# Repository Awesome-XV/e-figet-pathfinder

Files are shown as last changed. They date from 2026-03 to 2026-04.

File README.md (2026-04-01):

# e-figet-pathfinder
This is a project that allows you to play around with switches and LED's. It's a reaction game ... for now, I am planning to make a settings/page button that allows you to play different game modes and stuff. But now it's geared toward an *F1* style gameplay where the LED's close in on the center light and then they all go blank and it measures the time for you to let go of the "clutch" and hit the "accelerator". Maybe different racing types later??
I made this project as an intro into PCB's, circuits and soldering because it's my first physical project that I have done. I wanted to get into the hardware project and there was a nice guide, but no soldering guide so I get to do that on my own. So this is a bit later, and I added a battery compartment to it, it's now a mobile device and it doesn't have to be plugged in. I also am now planning to add a GT practice shifter to the code where you can practice shifting GT style. I also had to add 2 connectors so that I can solder the battery wires correctly.

# Some Pics





# BOM Table
| Name | Purpose | Quantity | Total Cost (USD) | Distributor | Link |
|---|---|:---:|---:|---|---|
| XIAO RP2040 | MC, controls everything | 1 | $4.68 | Digikey | [Buy](https://www.digikey.com/en/products/detail/seeed-technology-co-ltd/102010428/14672129) |
| LED RED 5MM | Lights up | 7 | $1.05 | Digikey | [Buy](https://www.digikey.com/en/products/detail/w%C3%BCrth-elektronik/151051RS11000/4490012) |
| Through Hole Resistors | For the LEDs | 10 | $0.22 | Digikey | [Buy](https://www.digikey.com/en/products/detail/stackpole-electronics-inc/CF18JT110R/1741570) |
| MX SWITCH 12V | Switch to trigger actions | 4 | $5.00 | Digikey | [Buy](https://www.digikey.com/en/products/detail/cherry-americas-llc/MX1A-C1NW/280855) |
| BLACK KEYCAPS | Keycaps for the MX switches | 1 | $5.95 | Digikey | [Buy](https://www.digikey.com/en/products/detail/adafruit-industries-llc/4997/14552180) |
| Battery Compartment | To hold the batteries | 1 | $1.77 | Digikey | [Buy](https://www.digikey.com/en/products/detail/keystone-electronics/2465/303814) |
| Connectors | To provide a place for the red and black wires to hook onto | 10 | $0.29 | Digikey | [Buy](https://www.digikey.com/en/products/detail/adam-tech/PH1-01-UA/9830231) |
| Diode | To prevent reverse current flow | 1 | $0.18 | Digikey | [Buy](https://www.digikey.com/en/products/detail/smc-diode-solutions/1N5817/21705460) |
| PCB | For connection | 1 | $2.00 | JLCPCB | N/A |
| Shipping | Move these parts | 1 | $10.29 | JLCPCB, Digikey | N/A |
| Tax | I have to pay | 1 | $2.22 | Digikey | N/A |
| Tariffs | Quantity means 5 products I have tax on | 5 | $0.79 | Digikey | N/A |
| **Total** | | | *$34.44* | | |

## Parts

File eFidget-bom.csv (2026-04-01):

Name | Purpose | Quantity | Total Cost (USD) | Link | Distributor
Connectors | To provide a place for the red and black wires to hook onto | 10 | 0.29 | https://www.digikey.com/en/products/detail/adam-tech/PH1-01-UA/9830231 | Digikey
Diode | To prevent reverse current flow | 1 | 0.18 | https://www.digikey.com/en/products/detail/smc-diode-solutions/1N5817/21705460 | Digikey
Through Hole Resistors | For the LEDS | 10 | 0.22 | https://www.digikey.com/en/products/detail/stackpole-electronics-inc/CF18JT110R/1741570 | Digikey
Battery Compartment | To hold the batteries | 1 | 1.77 | https://www.digikey.com/en/products/detail/keystone-electronics/2465/303814 | Digikey
Tax | I have to pay this | 1 | 2.22 |  | Digikey
Tarrifs | Worse version of tax (quantity means 5 products I have tax on) | 5 | 0.79 |  | Digikey
XIAO RP2040 | MC, controls everything | 1 | 4.68 | https://www.digikey.com/en/products/detail/seeed-technology-co-ltd/102010428/14672129 | Digikey
MX SWITCH 12V | Switch to trigger actions | 4 | 5.00 | https://www.digikey.com/en/products/detail/cherry-americas-llc/MX1A-C1NW/280855 | Digikey
BLACK KEYCAPS | Keycaps for the MX switches | 1 | 5.95 | https://www.digikey.com/en/products/detail/adafruit-industries-llc/4997/14552180 | Digikey
LED RED 5MM | Lights up | 7 | 1.05 | https://www.digikey.com/en/products/detail/w%C3%BCrth-elektronik/151051RS11000/4490012 | Digikey
Shipping | Move these parts! | 1 | 10.29 |  | JLCPCB, Digikey
PCB | For connection! | 1 | 2.00 |  | JLCPCB

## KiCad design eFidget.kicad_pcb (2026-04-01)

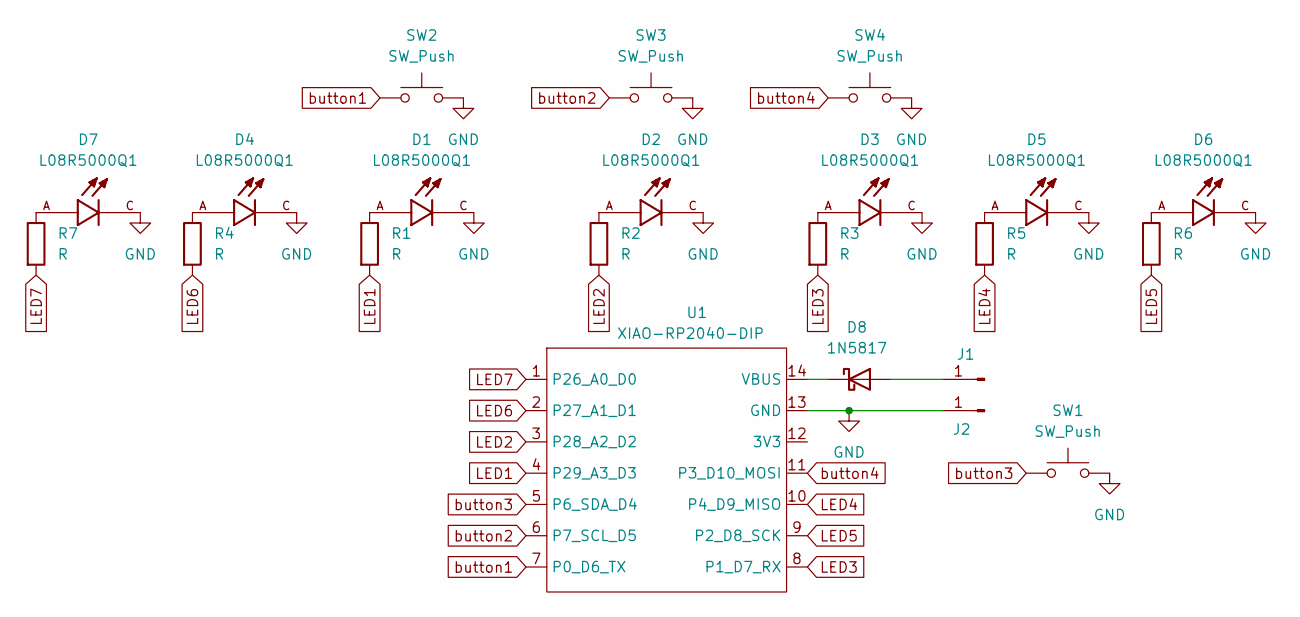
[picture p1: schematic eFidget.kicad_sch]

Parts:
D1, D2, D3, D4, D5, D6, D7: L08R5000Q1; LEDRD254W57D500H1070; PARTREV NA
D8: 1N5817; D_DO-41_SOD81_P10.16mm_Horizontal
J1, J2: Conn_01x01_Pin; PinHeader_1x01_P2.54mm_Vertical
R1, R2, R3, R4, R5, R6, R7: R; R_Axial_DIN0204_L3.6mm_D1.6mm_P5.08mm_Horizontal
SW1, SW2, SW3, SW4: SW_Push; SW_Cherry_MX_1.00u_PCB
U1: XIAO-RP2040-DIP

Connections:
GND: D1.C, D2.C, D3.C, D4.C, D5.C, D6.C, D7.C, J2.1, SW1.2, SW2.2, SW3.2, SW4.2, U1.13 (GND)
LED1: R1.2, U1.4 (P29_A3_D3)
LED2: R2.2, U1.3 (P28_A2_D2)
LED3: R3.2, U1.8 (P1_D7_RX)
LED4: R5.2, U1.10 (P4_D9_MISO)
LED5: R6.2, U1.9 (P2_D8_SCK)
LED6: R4.2, U1.2 (P27_A1_D1)
LED7: R7.2, U1.1 (P26_A0_D0)
unnamed: D1.A, R1.1
unnamed: D2.A, R2.1
unnamed: D3.A, R3.1
unnamed: D4.A, R4.1
unnamed: D5.A, R5.1
unnamed: D6.A, R6.1
unnamed: D7.A, R7.1
unnamed: D8.2 (A), J1.1
unnamed: D8.1 (K), U1.14 (VBUS)
button1: SW2.1, U1.7 (P0_D6_TX)
button2: SW3.1, U1.6 (P7_SCL_D5)
button3: SW1.1, U1.5 (P6_SDA_D4)
button4: SW4.1, U1.11 (P3_D10_MOSI)

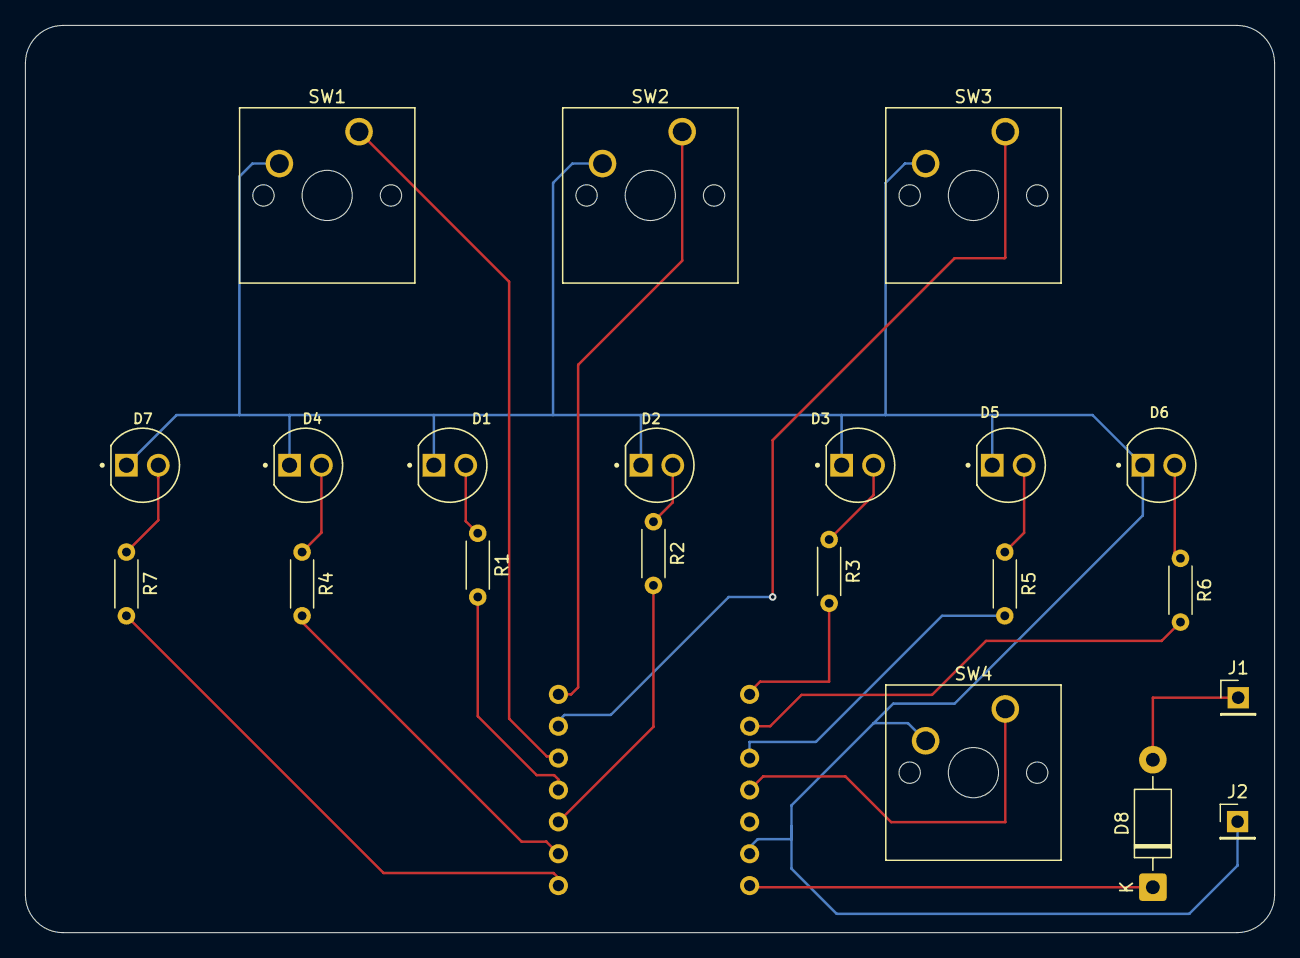
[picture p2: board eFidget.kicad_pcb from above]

Board: 2 copper layers, 99.5 x 72.3 mm, 22 parts (1 on the bottom side), 21 nets.

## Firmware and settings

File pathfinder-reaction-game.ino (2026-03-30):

// Quick Map of the pins for refrence
// D0 = Led 7 (Most right)
// D9 = Led 4
// D3 = Led 1
// D2 = Led 2 (Center)
// D7 = Led 3
// D8 = Led 5
// D1 = Led 6 (Most Left)

// D6 = Switch 1 (clutch)
// D5 = Switch 2 (TBD)
// D4 = Switch 3(accelerate)
// D10 = Switch 4 (Start)

const int LED_COUNT = 7;
const int LEDS[7] = { D0, D1, D9, D2, D3, D8, D7 };
const int BTN_CLUTCH = D6;
const int BTN_ACCELERATE = D4;
const int BTN_START = D5;

const int STEP = 800;
const int MIN_HOLD = 500;
const int MAX_HOLD = 7000;
const int TIMEOUT = 5000;

void allOn() {
  for (int i = 0; i < LED_COUNT; i++) {
    digitalWrite(LEDS[i], HIGH);
  }
}

void allOff() {
  for (int i = 0; i < LED_COUNT; i++) {
    digitalWrite(LEDS[i], LOW);
  }
}

void keyPress(int pin) {
  while (digitalRead(pin) == HIGH) {
    delay(5);
  }
}

void keyRelease(int pin) {
  while (digitalRead(pin) == LOW) {
    delay(5);
  }
}

void falseStart() {
  allOff();
}

bool checkFalseStart() {
  if (digitalRead(BTN_ACCELERATE) == LOW) {
    falseStart();
    return true;
  }

  if (digitalRead(BTN_CLUTCH) == HIGH) {
    falseStart();
    return true;
  }

  return false;
}

void showResult(long reactionTime) {
  char digits[8];
  sprintf(digits, "%07ld", reactionTime);
  for (int i = 0; i < 7; i++) {
    int count = digits[i] - '0';

    if (count == 0) continue;
    for (int x = 0; x < count; x++) {
      digitalWrite(LEDS[i], HIGH);
      delay(250);
      digitalWrite(LEDS[i], LOW);
      delay(200);
    }

    delay(500);
  }
}

void setup() {
  Serial.begin(115200);
  for (int i = 0; i < LED_COUNT; i++) {
    pinMode(LEDS[i], OUTPUT);
    digitalWrite(LEDS[i], LOW);
  }

  pinMode(BTN_START, INPUT_PULLUP);
  pinMode(BTN_CLUTCH, INPUT_PULLUP);
  pinMode(BTN_ACCELERATE, INPUT_PULLUP);

  randomSeed(analogRead(A3));
  for (int i = 0; i < LED_COUNT; i++) {
    digitalWrite(LEDS[i], HIGH);
    delay(80);
  }

  delay(300);
  allOff();
}

void loop() {
  while (digitalRead(BTN_START) == HIGH || digitalRead(BTN_CLUTCH) == HIGH) {
    delay(5);
  }

  keyRelease(BTN_START);
  delay(500);

  int seqL[4] = {0, 1, 2, 3};
  int seqR[4] = {6, 5, 4, 3};

  for (int step = 0; step < 3; step++) {
    digitalWrite(LEDS[seqL[step]], HIGH);
    digitalWrite(LEDS[seqR[step]], HIGH);
    delay(STEP);
    if (checkFalseStart()) {
      return;
    }
  }

  digitalWrite(LEDS[3], HIGH);
  
  if (checkFalseStart()) {
    return;
  }

  long holdEnd = millis() + random(MIN_HOLD, MAX_HOLD);

  while (millis() < holdEnd) {
    if (checkFalseStart()) {
      return;
    }
  }

  allOff();

  long goTime = millis();
  bool clutchReleased = false;
  long reactionTime = -1;

  while (millis() - goTime < TIMEOUT) {
    if (!clutchReleased && digitalRead(BTN_CLUTCH) == HIGH) {
      clutchReleased = true;
    }
    if (clutchReleased && digitalRead(BTN_ACCELERATE) == LOW) {
      reactionTime = millis() - goTime;
      break;
    }
  }

  if (reactionTime < 0) {
    return;
  }

  showResult(reactionTime);
}

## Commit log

2026-03-24 Adding KiCad Files
    All KiCad files used
    [eFidget.kicad_pcb, eFidget.kicad_sch]
2026-03-24 Add Prod Zip Files
    These are the files used to actually request the PCB
2026-03-25 Update README
    Include info about project and make the BOM available in the README.
2026-03-30 Add BOM
    [eFidget-bom.csv]
2026-03-30 Update BOM
2026-03-30 Add Arduino Firmware
2026-04-01 Update all files with new submission
    [eFidget-bom.csv, eFidget.kicad_pcb, eFidget.kicad_sch]
2026-04-01 Update README
    Added new images and updated project description with additional details about battery compartment and connectors.
